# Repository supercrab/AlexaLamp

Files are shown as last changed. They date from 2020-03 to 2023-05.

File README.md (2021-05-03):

# AlexaLamp

This project was to create an Alexa voice controlled lamp with adjustable brightness. The lamp can also controlled using a rotary encoder with built in push switch or via a web page provided

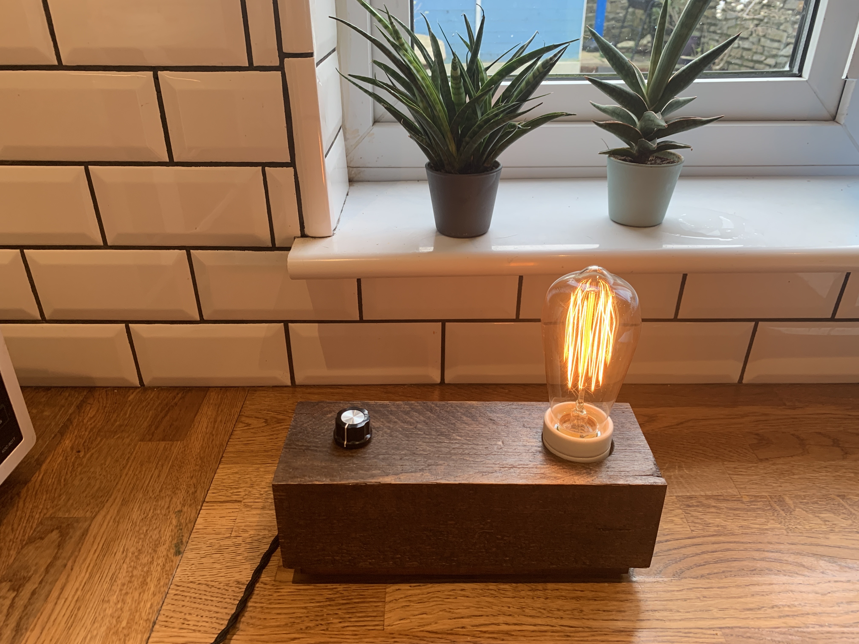
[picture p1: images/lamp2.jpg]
Lamp looking cool


## Components

Here is a list of the essential components you will need.  Shop around for the components as you should be able to find some good deals if you purchase from China/Banggood.

### Essential

* [Echo Dot](https://www.amazon.co.uk/Echo-Dot-3rd-Gen-Charcoal/dp/B07PJV3JPR) - for testing or final use but not mandatory as the lamp has a standalone mode and local website
* [Wemos D1 Mini or compatible](https://wiki.wemos.cc/products:d1:d1_mini) - I used a cheap clone
* [HLK-PM01 AC-DC 220V to 5v mini power supply module](http://www.hlktech.net/product_detail.php?ProId=54)
* [Robotdyn AC Light Dimmer Module](https://robotdyn.com/ac-light-dimmer-module-1-channel-3-3v-5v-logic-ac-50-60hz-220v-110v.html)
* [Rotary encoder with push switch](https://uk.pi-supply.com/products/rotary-encoder-push-switch) or [KY-040 rotary encoder module](https://uk.banggood.com/KY-040-Rotary-Decoder-Encoder-Module-AVR-PIC-p-914010.html)
* [Vintage E27 bulb holder ceramic](https://www.ebay.co.uk/itm/Vintage-E27-Bulb-Holder-Ceramic-Industrial-Lamp-Lighting-Antique-Retro-Edison/253903670767) you could use a bayonet holder if you preferred
* [MF-A03 control knob](https://www.google.com/search?q=MF-a03) or something similar
* [2 core twisted cable](https://www.ebay.co.uk/itm/2-Core-Twist-Braided-Fabric-Cable-Vintage-Electric-Wire-Flexible-Lighting-Cord/312959065511) because it's pretty
* [240v mains plug](https://www.ebay.co.uk/sch/i.html?_odkw=13A+BLACK+plug&_nkw=13A+fused+BLACK+plug) for UK builders

### Optional

These depend on how you are going to mount your bulb and what finish you fancy for your enclosure.

* [M10 hollow threaded rod](https://lightingspares.co.uk/collections/threaded-rods)
* [M10 threaded nut](https://lightingspares.co.uk/products/oaks-oa16-metal-10mm-threaded-nut)
* [M10 penny washer](https://www.toolstation.com/penny-washer/p90716)
* [Liberon based wood dye dark oak](https://www.screwfix.com/p/liberon-ethanol-based-wood-dye-dark-oak-250ml/3102f)
* [Liberon superior Danish oil clear](https://www.screwfix.com/c/decorating/wood-oil/cat850452)
* [Felt pads](https://www.toolstation.com/felt-gard-felt-pad-set/p95753)

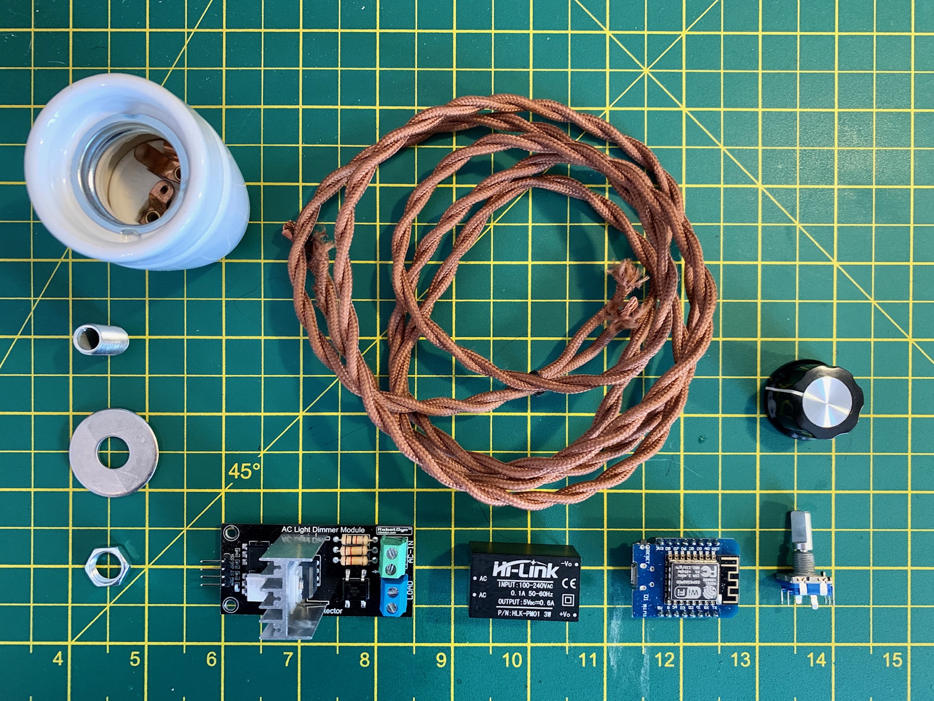
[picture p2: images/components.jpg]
Project components


## Schematic

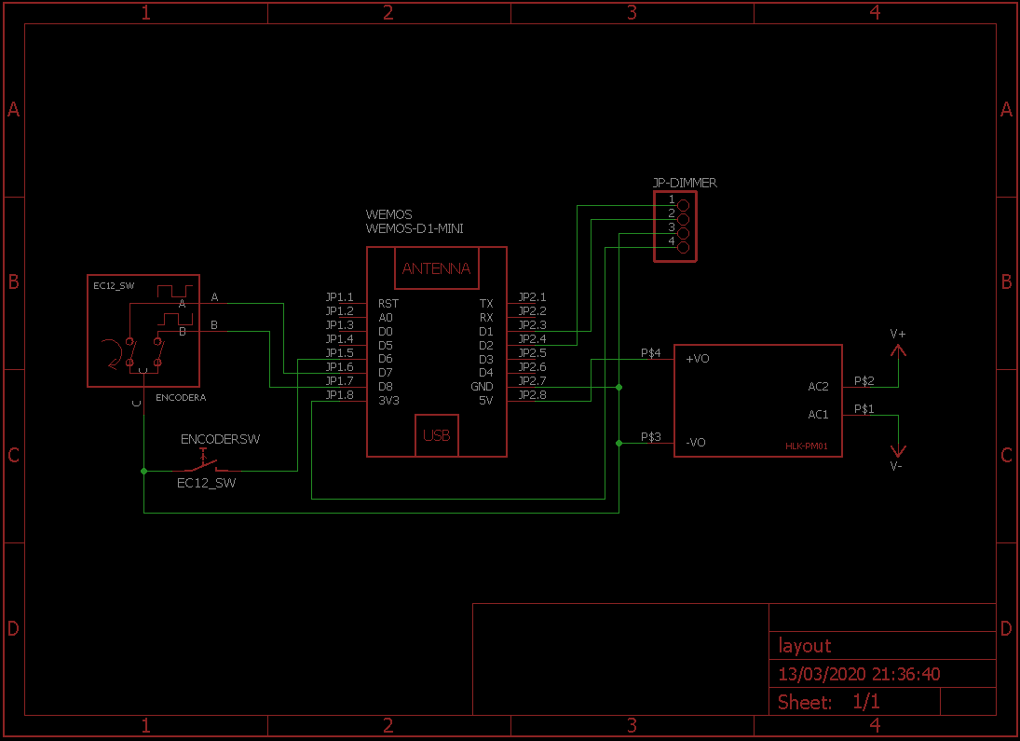
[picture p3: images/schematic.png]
Project schematic


**NOTE: the direction that the rotary encoder affects lamp brightness can be reversed by swapping digital inputs 6 & 7 or can be configured in the web front end**

## Wooden Enclosure

* The enclosure is made up of 2 parts: a wooden block (roughly 4 inches by 3 inches) and a planed wood base that screws into the block and locks the electronics away
* The wooden block is hollowed out so that there is enough space for all the components
* The components are arranged inside the cavity **ensure that wires carrying 240v are kept short and well away from the low voltage Wemos and dimmer control circuitry. The high voltage can cause flickering with brightness control if the wires were too close!**
* A cloth was used to apply 3 coats of [Liberon based wood dye dark oak](https://www.screwfix.com/p/liberon-ethanol-based-wood-dye-dark-oak-250ml/3102f) to give some colour.  You can also use [Liberon based wood dye light oak](https://www.screwfix.com/p/liberon-ethanol-based-wood-dye-light-oak-250ml/8322F) or mix them both dyes to create a new shade
* A peice of wirewool was used to apply 3 coats of [Liberon superior Danish oil clear](https://www.screwfix.com/c/decorating/wood-oil/cat850452) which gave the wood a shine and made it waterproof
* Once I was certain everything worked, the wooden base was screwed into the block and [felt pads](https://www.toolstation.com/felt-gard-felt-pad-set/p95753) were used to hide the screws
* If there is a problem you can always update the system over-the-air by navigating to the update page (http://lamp.local:81/update) and uploading a custom firmware (.bin file from the build process)

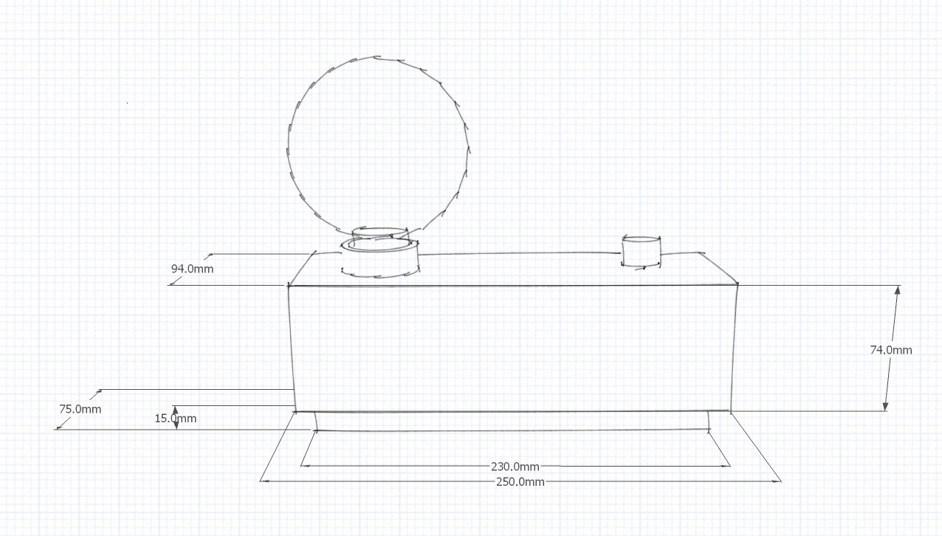
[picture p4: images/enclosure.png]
Project enclosure


## Instructions

* Build the circuit on a breadboard **be careful with the 240v side - turn it off when not in use**
* Download and install the following Arduino libraries
	* [Dimmable-Light-Arduino (Fabiano Riccardi)](https://github.com/fabiuz7/Dimmable-Light-Arduino)
	* [AsyncWiFiManager (lbussy)](https://github.com/lbussy/AsyncWiFiManager)
	* [Encoder (Paul Stoffregen)](https://github.com/PaulStoffregen/Encoder)
	* [JC_Button (Jack Christensen)](https://github.com/JChristensen/JC_Button)
	* [ESPAsyncWebServer (me-no-dev)](https://github.com/me-no-dev/ESPAsyncWebServer)
* Set IwIP Varaint: "v1.4 Higher Bandwidth"
* Set board to: D1 R2 & mini
* Download the AlexaLamp [code](https://github.com/supercrab/AlexaLamp), compile and upload code to Wemos D1 or compatible device
* Test everything works as expected (see below for how to setup wifi and change modes)
* Make the circuit permenant by installing into your wooden block or whatever space you have.

## How to use

The lamp has 2 modes: wifi (default) and standalone.  

To change the mode:

* Turn off the 240v supply to the lamp
* Hold the rotary encoder push switch down
* Turn on 240v supply
* Wait until the lamp starts to slowly flash
* Release the push switch
* The number of flashes seen will tell you which mode the lamp is in.  1 flash indicates standalone and 2 flashes for wifi/Alexa voice control mode.

### Wifi mode (default)

* When the lamp is turned on for the first time it will create an unsecured wifi hotspot called lamp-setup
* You can use your phone to connect to the hotspot and enter your wifi network credentials
* Once your credentials are verified, the hotspot will disappear and your wifi settings will be stored on the device
* The lamp will now connect to your network and you will be able to control the lamp using the rotary encoder
* Say "Alexa, discover devices" or go to the Alexa app and hit "Add Device", "Other", "Discover devices"
* Your lamp is now ready!

**If you connect the lamp to the mains and it cannot connect to a network using its stored settings then it will create a new hotspot and wait for new credentials.  While in this state, the rotary encoder will not work until the new wifi credentials are entered but you can still change the lamp's mode using the method described previously.**

### Standalone mode

* This mode does not connect to any wifi networks or create any hotspots
* Plain old lamp
* Rotary encoder works straight away

#### Lamp Webpages

* When in wifi mode you may navigate to lamp.local to access the lamp's web frontend.
* If you can't access the device this way then use a network discovery program to find the local IP address.

##### UI - Home Page

* Control state and brightness
* Change the device's Alexa name

#### UI - Settings

* Change mode: wifi or standalone
* Invert the rotary encoder, if you turning the knob does the opposite to what you want it to
* Change encoder knob sensitivity
* Change the frequency the device verifies its wifi connection.
* Enable atomatic updates (checked every 24 hours)

##### UI - Update

* Manually upload custom firmware (arduino .bin file) or start a remote update (if available)
* View the devices

##### UI - About

* Displays system version and information

### Alexa voice controls

Once setup, you can use different ways to invoke Alexa to modify the lamp's state:

* Alexa, turn lamp on
* Alexa, turn on lamp
* Alexa, set lamp to fifty (50% of brightness)
* Alexa, set lamp to one hundred (100% brightness)

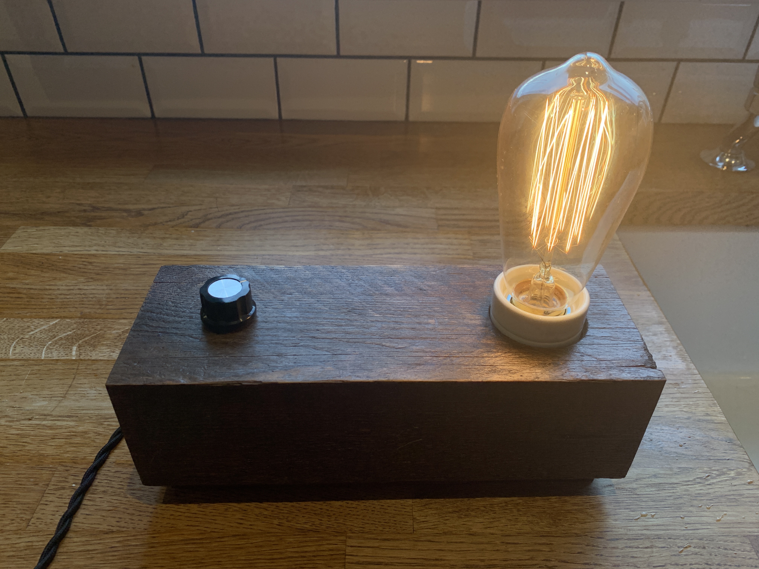
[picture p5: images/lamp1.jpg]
Lamp looking cool

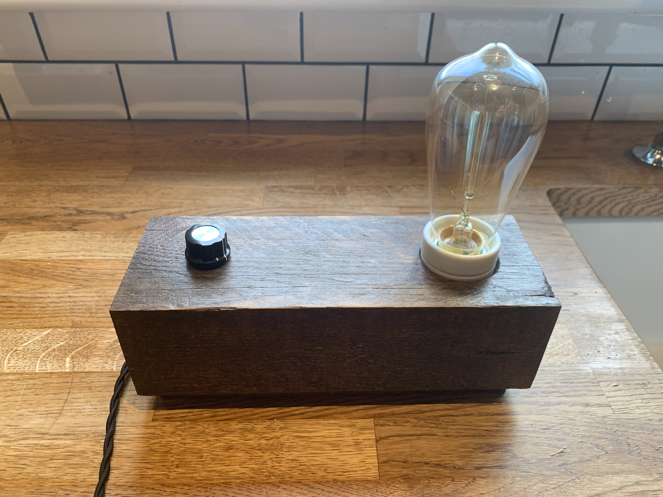
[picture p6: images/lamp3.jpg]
Lamp looking cool


# Credits

Developed on a WeMos D1 mini clone, using Arduino IDE 1.8.1 with ESP8266 Core 2.7.4

This project would not have been possible without the kind development of others on GitHub!  Click on a name to see the authors' GitHub page

* [Fauxmoesp (vintlabs)](https://github.com/vintlabs)
* [Encoder (Paul Stoffregen)](https://github.com/PaulStoffregen)
* [ESPAsncWebServer (me-no-dev)](https://github.com/me-no-dev)
* [AsynchWifiManager (lbussy)](https://github.com/lbussy)
* [JC_Button (Jack Christensen)](https://github.com/JChristensen)
* [Dimmable-Light-Arduino (Fabiano Riccardi)](https://github.com/fabiuz7)

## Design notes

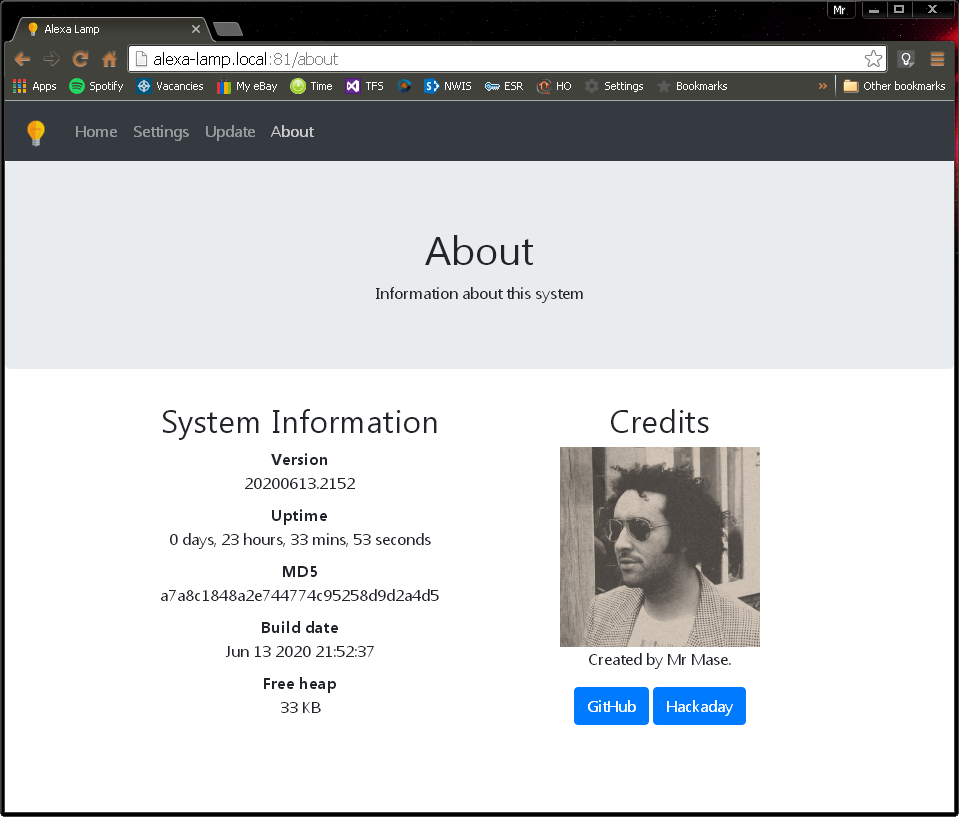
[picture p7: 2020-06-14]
images/web-about.png

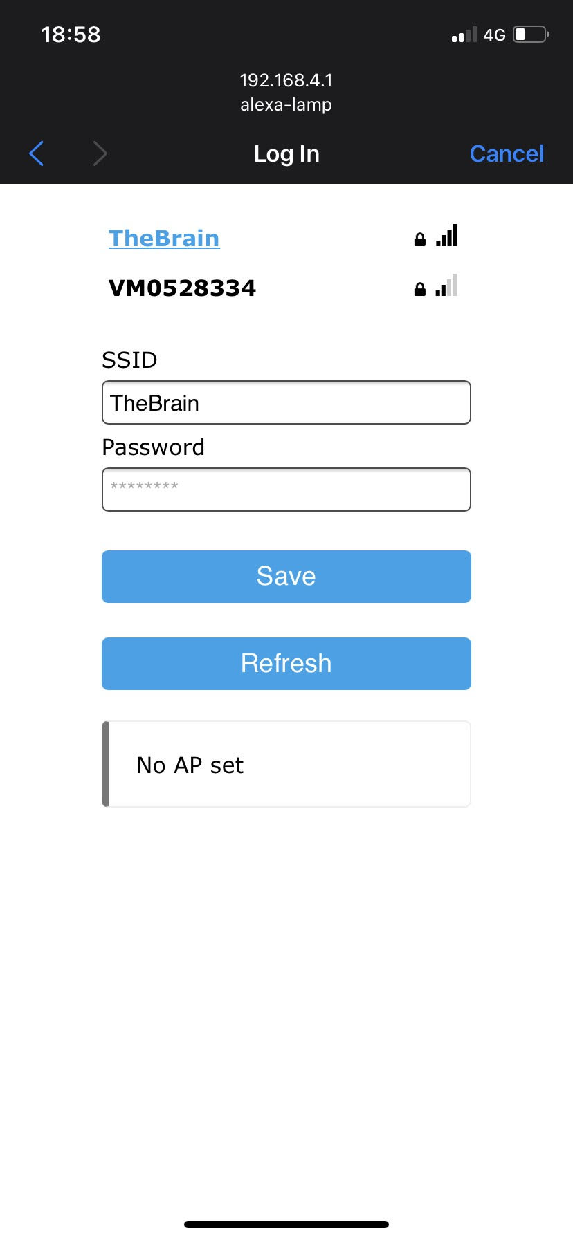
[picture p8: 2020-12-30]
images/wifi-manager-scan.jpg

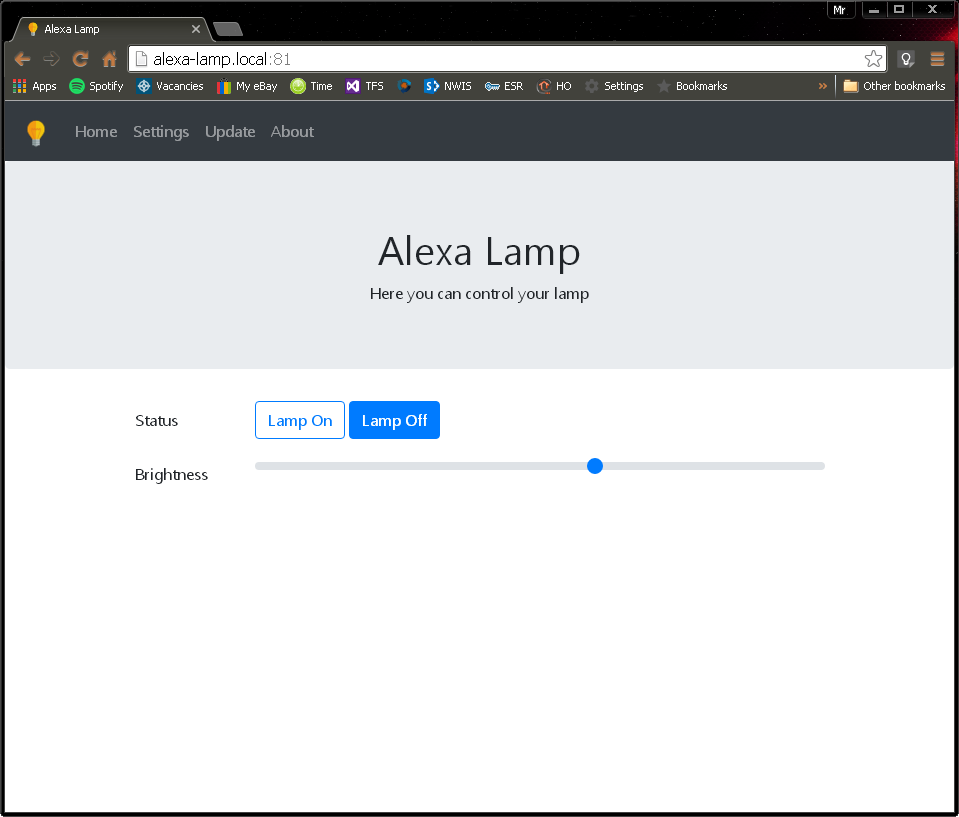
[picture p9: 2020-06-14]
images/web-home.png

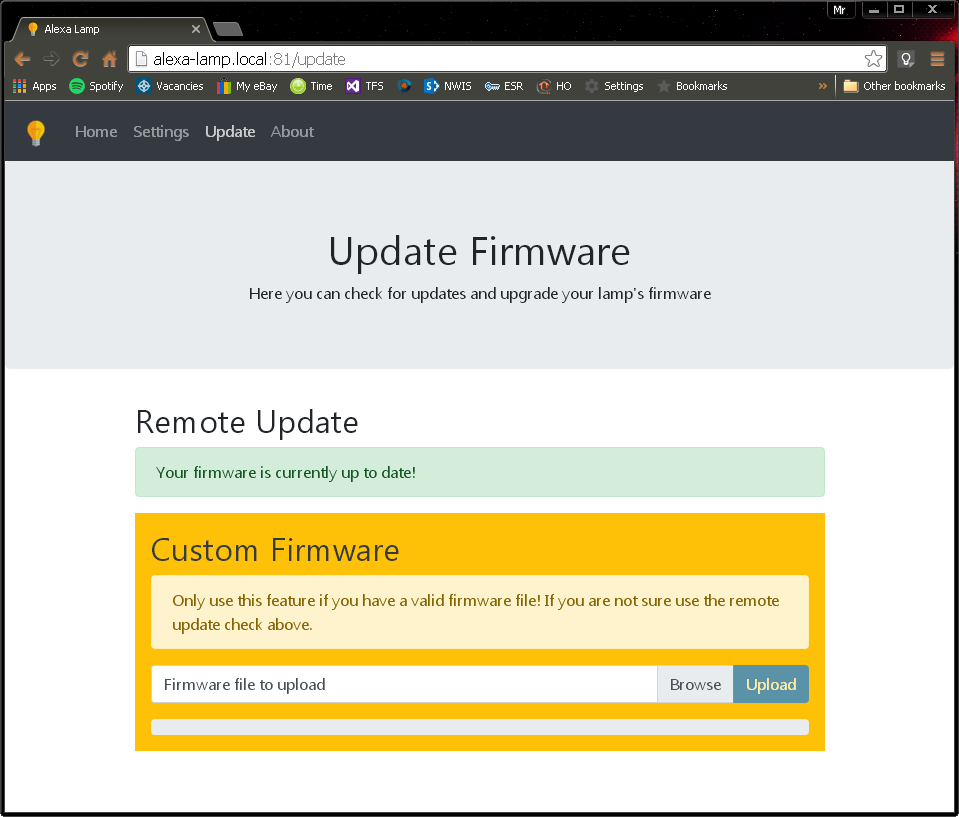
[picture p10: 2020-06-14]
images/web-update.png

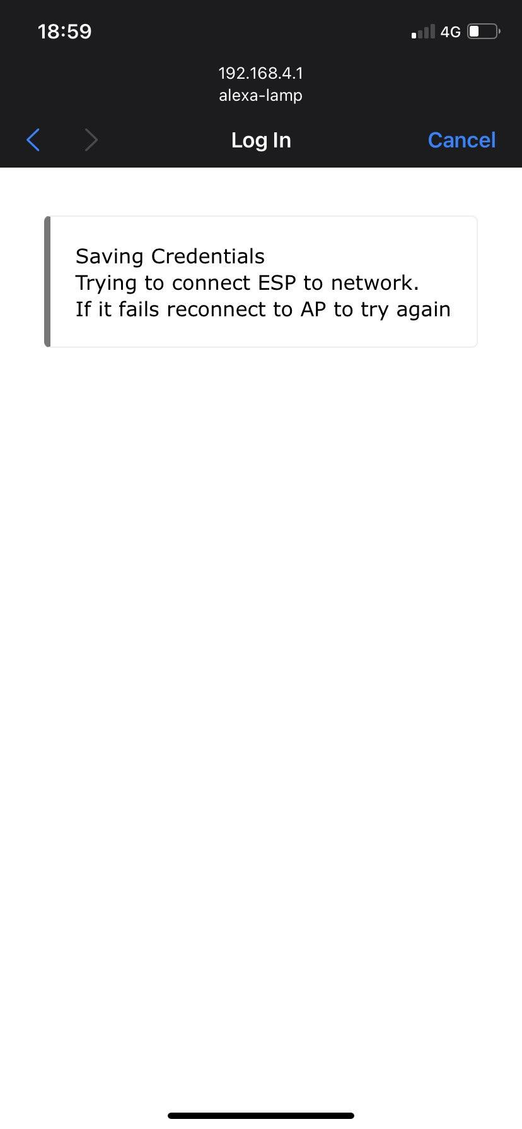
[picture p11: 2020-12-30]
images/wifi-manager-saving.jpg

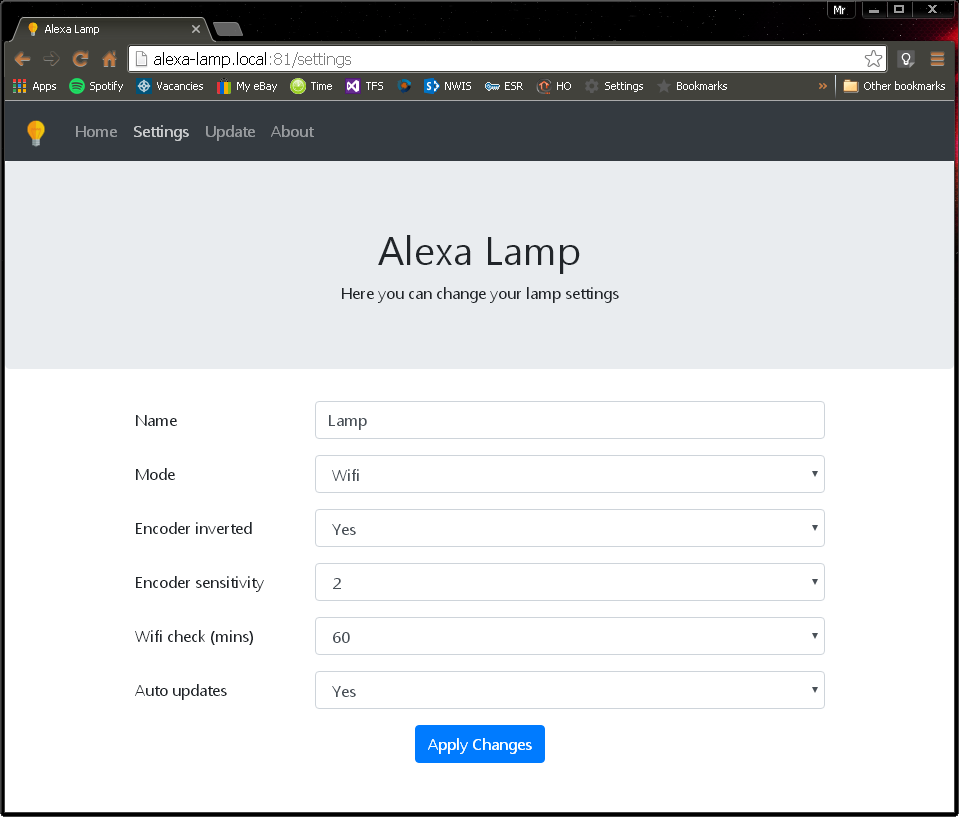
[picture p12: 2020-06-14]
images/web-settings.png

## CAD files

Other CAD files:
sketchup/enclosure.skp

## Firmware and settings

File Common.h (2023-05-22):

#ifndef Common_h
#define Common_h

// ---------------------------------------------------------
// Macros
// ---------------------------------------------------------

// Macro for calculating array length
#define ARRAY_LENGTH(array) (sizeof((array))/sizeof((array)[0]))

// ---------------------------------------------------------
// Hardware settings (these can be changed to match the hardware)
// ---------------------------------------------------------

// Zero cross detection pin
#define ZERO_CROSS_PIN	D1

// Triac pin 
#define TRIAC_PIN		D2 

// Encoder switch
#define ENCODER_SWITCH_PIN	D5

// Encoder A pin
#define ENCODER_A_PIN	D6

// Encode B pin 
#define ENCODER_B_PIN	D7

// ---------------------------------------------------------
// Default user settings - these can be changed
// ---------------------------------------------------------

// Initial device name for Alexa purposes 
#define DEFAULT_ALEXA_NAME	"Lamp"

// Initial mode can be WIFI or STANDALONE (WIFI is best)
#define DEFAULT_MODE WIFI

// How often should we check wifi is connected in minutes? (0, 1, 5, 15, 30, 60)
#define DEFAULT_WIFI_CONNECTED_CHECK_MINS 1

// How sensitive the encoder is 
// (1 = slowest, higher means more change)
#define DEFAULT_ENCODER_SENSITIVITY 2

// Default whether we want the encoder direction flipped
#define DEFAULT_ENCODER_INVERTED	false

// Default whether we want automatic updates (check period is defined above)
#define DEFAULT_AUTOMATIC_UPDATES	true

// ---------------------------------------------------------
// Initial lamp settings - these can be changed
// ---------------------------------------------------------

// Initial lamp brightness when turned on for the first time
#define INITIAL_BRIGHTNESS 255

// Initial lamp status (off for safety reasons)
#define INITIAL_STATE	false

// ---------------------------------------------------------
// Software settings - should not need changing
// ---------------------------------------------------------

// Enable MDNS
// The local URL for accessing the web config is http://lamp.local
// Running MDNS creates extra processing for the MDNS traffic
// If you're not bothered by having a MDNS name for the device then comment out this line
#define ENABLE_MDNS

// Serial baudrate 
#define SERIAL_BAUDRATE 115200

// Admin port for admin web page
#define ADMIN_WEB_PORT 81

// Define how many characters the device's alexa name can be
#define ALEXA_NAME_LENGTH	32

// Network hostname and for MDNS
#define HOSTNAME	"lamp"

// Access point created to configure Wifi settings
#define ACCESS_POINT_NAME "lamp-setup"

// Number of hours to check for automatic updates
#define AUTO_UPDATE_CHECK_PERIOD_HOURS 24

// ---------------------------------------------------------
// Remote update settings - should not be changed
// ---------------------------------------------------------

// Uodate server
#define HTTP_UPDATE_SERVER "supercrab.co.uk"

// Update path
#define HTTP_UPDATE_PATH "/update/"

// Device ID for http update
#define HTTP_UPDATE_DEVICE_ID "alexalamp"

// ---------------------------------------------------------
// Enums
// ---------------------------------------------------------

// Lamp mode
enum operation_t{
	STANDALONE, 
	WIFI
};

// Holds current update status
enum updateStatus_t{
	UPDATE_STATUS_IDLE,				// 0 - not updating
	UPDATE_STATUS_NO_UPDATES,		// 1 - checked for updates but there were nonte
	UPDATE_STATUS_LOCAL_UPDATE,		// 2 - update by an uploaded firmware
	UPDATE_STATUS_REMOTE_UPDATE,	// 3 - update by checking remote server
	UPDATE_STATUS_FAILED,			// 4 - update failed
	UPDATE_STATUS_OK				// 5 - updated worked
};

#endif

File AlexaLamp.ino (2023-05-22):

//	____ _    ____ _  _ ____       _    ____ _  _ ___  
//	|__| |    |___  \/  |__|       |    |__| |\/| |__] 
//	|  | |___ |___ _/\_ |  |       |___ |  | |  | |    
//				with brightness control
//
//	by Supercrab
//	https://github.com/supercrab
//
//	Developed on a WeMos D1 mini clone, using Arduino IDE 1.8.1 with ESP8266 Core 2.7.4
//
//  This code is intended to work on cheap ESP8266 devices
//
//	Thanks to the developers of the libraries I found on GitHub!
//
// TODO
// ====
// 
// * Lamp might flickers with values < 100, this seems to be down to the newer ESP core
// * MDNS seems to be flakey especially after you setup wifi using the automatic hotspot
//   hopefully fixed in a newer version of the ESP8266 core (not related to any code here)
// * Fauxmo - when 2 devices have the same Alexa name and you browse to the device on port 80, it causes a restart
//  (might be fixed due to the MAC address not being static now)
//
// ---------------------------------------------------------
// Main configuration
// ---------------------------------------------------------
#include "Common.h"

// ---------------------------------------------------------
//  * Fauxmoesp (vintlabs)
//  https://github.com/vintlabs/fauxmoESP
//	* Fauxmoesp redirect functionality (Enrico A.)
//	https://bitbucket.org/xoseperez/fauxmoesp/issues/101/fauxmoesp-with-esp8266webserver
// ---------------------------------------------------------
#include "fauxmoESP.h"

// ---------------------------------------------------------
//	* Dimmable-Light-Arduino (Fabiano Riccardi)
//	https://github.com/fabiuz7/Dimmable-Light-Arduino
// ---------------------------------------------------------
#include <dimmable_light.h>

// ---------------------------------------------------------
//	* AsyncWiFiManager (lbussy)
//	https://github.com/lbussy/AsyncWiFiManager
// ---------------------------------------------------------
#define WM_ASYNC // Turn on Async mode
#include <AsyncWiFiManager.h>

// ---------------------------------------------------------
//	* Encoder (Paul Stoffregen)
//	https://github.com/PaulStoffregen/Encoder
// ---------------------------------------------------------
#include <Encoder.h>

// ---------------------------------------------------------
//	* JC_Button (Jack Christensen)
//	https://github.com/JChristensen/JC_Button
// ---------------------------------------------------------
#include <JC_Button.h>

// ---------------------------------------------------------
// System libraries
// ---------------------------------------------------------
#ifdef ENABLE_MDNS
	#include <ESP8266mDNS.h>
#endif
#include <ESP8266HTTPClient.h>
#include "coredecls.h"

// ---------------------------------------------------------
// Project libraries
// ---------------------------------------------------------
#include "SoftwareTimer.h"
#include "Config.h"
#include "AdminWebServer.h"
#include "HttpUpdate.h"

fauxmoESP fauxmo;
DimmableLight light(TRIAC_PIN);
Encoder encoder(ENCODER_A_PIN, ENCODER_B_PIN);
Button button(ENCODER_SWITCH_PIN);
SoftwareTimer timerWifiCheck;
SoftwareTimer timerAutomaticUpdate;
AdminWebServer server(ADMIN_WEB_PORT);
Config config;

// Calculate PWM constant
const float pwm = (255 * log10(2))/log10(255);

// Previous encoder value
int16_t encoderOldValue = 0;

// Initialise serial port and communications
void setupSerial(){
	Serial.begin(SERIAL_BAUDRATE);
	Serial.println();
	Serial.println();
	Serial.println(F("-----------------------------------"));
	Serial.println(F("Application started"));
	Serial.println(F("-----------------------------------"));
	Serial.println();
}

// Set the brightness based on a correction for non linear brightness
// https://diarmuid.ie/blog/pwm-exponential-led-fading-on-arduino-or-other-platforms
void setLightBrightness(uint8_t value){
	uint8_t brightness = correctPwmBrightness(value);
	light.setBrightness(brightness);
}

// Function to correct for non linear brightness when using PWM
//
// Works but the light was practically off at brightness value 100
// Needs some sort of light calibration which is probably different for all bulbs, so disabled for now
uint8_t correctPwmBrightness(uint8_t value){
	return value;
	/*
	if (value == 255) {
		return 255;
	}
	return pow(2, (value / pwm)) - 1;
	*/
}

// Callback for when remote update starts
void remoteUpdateStarted() {
	Serial.println(F("UPDATE: HTTP update process started"));
}

// Callback for when remote update completes
void remoteUpdateFinished() {
	Serial.println(F("UPDATE: HTTP update process finished"));

	// Store current lamp state so that we can restart and return to what the lamp was doing
	config.systemUpdated();

	// Turn light off before restarting because the light (timer) becomes unstable
	setLightBrightness(0);
}

// Info on using the updater class:
// https://arduino-esp8266.readthedocs.io/en/latest/ota_updates/readme.html
// https://github.com/esp8266/Arduino/blob/16319da63d4e8f7b4d029bfe667ed1b370a485bb/doc/ota_updates/readme.rst
// 
// My changes to the ESP8266 WebUpdater:
//
// 1. New method on web updater to prevent an update if we just want to check if one is available
t_httpUpdate_return update(bool install){

	// Flash our built in LED
	ESPhttpUpdate.setLedPin(LED_BUILTIN, LOW);

	// Set if we actually want to install the update if there is one
	ESPhttpUpdate.installUpdate(install);

	// If we're installing the update, set a callback to let the main program know the update has finished
	if (install){
		ESPhttpUpdate.onStart(remoteUpdateStarted);
		ESPhttpUpdate.onEnd(remoteUpdateFinished);
	}
	
	// Old way - works perfectly but is deprecated 
	t_httpUpdate_return ret = ESPhttpUpdate.updateNew(HTTP_UPDATE_DEVICE_ID, HTTP_UPDATE_SERVER, 80, HTTP_UPDATE_PATH);

	// New way - no worky, gives me a 301 (moved permenantly error), probably my host
	/*
	WiFiClient client;
	t_httpUpdate_return ret = ESPhttpUpdate.update(client, "http://supercrab.co.uk/update");
	*/

	// Handle returned result
	switch(ret) {
		case HTTP_UPDATE_AVAILABLE: 

			// This code is only executed when install = false
			// If install = true, then the system is updated and rebooted before it gets here
			Serial.println(F("UPDATE: available!"));
			break;

		case HTTP_UPDATE_FAILED:

			// Update was available but it failed
			Serial.println(F("UPDATE: failed!"));
			Serial.println(ESPhttpUpdate.getLastErrorString());
			if (install){
				config.setUpdateStatusFailed(ESPhttpUpdate.getLastErrorString());
			}
			break;

		case HTTP_UPDATE_NO_UPDATES:

			// There are not updated
			Serial.println(F("UPDATE: not available"));
			if (install){
				config.setUpdateStatusNoUpdates();
			}
			break;

		case HTTP_UPDATE_OK:
			// Here for completeness as this is not called because
			// a successful update causes the system to be rebooted)
			break;
	}
	return ret;
}

// Pulse the light 
void pulseLight(uint8_t times = 1){

	for (uint8_t t = 0; t < times; t++){

		// Ramp brightness up
		for (uint8_t b = 0; b < 255; b++){
			light.setBrightness(b);
			delay(6);
		}

		// Wait a bit at maximum
		delay(250);

		// Ramp brightness down
		for (uint8_t b = 255; b > 0; b--){
			light.setBrightness(b);
			delay(6);
		}
	}
}

// Setup hostname
void setupHostname(){

	Serial.print(F("WIFI: setting up hostname: ")); Serial.println(HOSTNAME);

	// Set the network host name
	WiFi.hostname(HOSTNAME);
}

// Callback when connecting to previous WiFi fails
void wifiManagerCallback(AsyncWiFiManager *myWiFiManager) {

	Serial.println(F("WIFI: entered configuration mode, creating access point"));
	Serial.println(WiFi.softAPIP());
	Serial.println(myWiFiManager->getConfigPortalSSID());
}

// Setup MDNS
void setupMDNS(){

	// Try and give us a name MDNS
	Serial.print(F("MDNS: setting up host as ")); 
	Serial.print(HOSTNAME);
	Serial.println(F(".local"));

	MDNS.close();
	if (!MDNS.begin(HOSTNAME)) {
		Serial.println(F("MDNS: failed"));
	}
	else{
		// Broadcast our http web server on admin port
		MDNS.addService("http", "tcp", ADMIN_WEB_PORT);
		Serial.println(F("MDNS: OK!"));
	}
}

// Setup Wifi
void setupWifiManager() {

	Serial.println(F("WIFI: starting connection manager"));

	// AsyncWiFiManager intialization. Once its business is done, there is no need to keep it around
	AsyncWiFiManager wifiManager;

	// set callback that gets called when connecting to previous WiFi fails, and enters Access Point mode
	wifiManager.setAPCallback(wifiManagerCallback);

	// fetches ssid and pass and tries to connect
	// if it does not connect it starts an access point with the specified name
	// and goes into a blocking loop awaiting configuration
	if (!wifiManager.autoConnect(ACCESS_POINT_NAME)){

		Serial.println(F("WIFI: failed to connect and hit timeout"));

		// reset and try again, or maybe put it to deep sleep
		ESP.restart();
		delay(1000);
	} 
	else {
		// The wifi manager has connected us!
		Serial.printf("WIFI: OK!  SSID: %s, IP address: %s\n", WiFi.SSID().c_str(), WiFi.localIP().toString().c_str());
	}
}

// Setup rotary encoder button
void setupButton(){
	button.begin();
}

// Setup rotary encoder
void setupRotaryEncoder(){
	setEncoderValue();
}

// Setup dimmer
void setupDimmer(){
	static bool dimmerInitialised = false;

	// only update dimmer if not updated
	if (!dimmerInitialised){
		DimmableLight::setSyncPin(ZERO_CROSS_PIN);
		DimmableLight::begin();
		dimmerInitialised = true;
	}
}

// Setup fauxmo library
void setupFauxmo(){

	fauxmo.createServer(true); 
	fauxmo.setPort(80); // for Gen3 devices
	fauxmo.setRedirect(ADMIN_WEB_PORT); // custom method to direct HTTP traffic on port 80 to custom port
	fauxmo.enable(true);

	// Add virtual device
	fauxmo.addDevice(config.getDeviceName());

	// Lamda expresison to handle light control  
	fauxmo.onSetState([](byte deviceId, const char* deviceName, bool deviceState, unsigned char value){

		// Output what we received
		Serial.printf("FAUXMO: device ID #%d (%s) state: %s value: %d\n", deviceId, deviceName, deviceState ? "ON " : "OFF", value);
		
		// Is the device matched?
		if (strcmp(deviceName, config.getDeviceName()) == 0) {

			// Store light state
			config.setState(deviceState);

			// Store light brightness
			config.setBrightness(value);

			// Set light brightness
			setLightBrightness(config.getState() ? config.getBrightness() : 0);

			// Set the rotary encolder value to current brightness (invert if required)
			setEncoderValue();
		} 
	});

	Serial.print(F("FAUXMO: initiated device called: "));
	Serial.println(config.getDeviceName());
}

// Setup webserver
void setupWebServer(){
	server.begin(&config);
}

// Setup a timer to periodically check wifi status
void setupWifiCheckTimer(){

	// Lambda expersion  to check wifi status is connected 
	timerWifiCheck.setCallback([](void){
		
		Serial.print("WIFI STATUS: ");

		// Check wifi status
		if (WiFi.status() != WL_CONNECTED){

			Serial.println("BAD!  Restarting device...");

			// Restart board and try and reconnect or enter AP mode
			ESP.restart();

			// Wait a while for the restart to kick in
			delay(5000);
		}
		else{
			Serial.println("OK");
		}
	});

	// Set the timer interval and start
	timerWifiCheck.setIntervalMinutes(config.getWifiCheckInterval()); 
	timerWifiCheck.start();
}

// Setup a timer to periodically check for automatic updates
void setupAutomaticUpdateTimer(){

	// Lambda expersion to run automatic update check
	timerAutomaticUpdate.setCallback([](void){

		// Check update - if update does occur the system is automatically restarted
		Serial.println(F("AUTO UPDATE: checking!"));
		updateSystem();
	});

	// Set the timer interval and start
	timerAutomaticUpdate.setIntervalHours(config.getAutomaticUpdates() ? AUTO_UPDATE_CHECK_PERIOD_HOURS : 0); 
	timerAutomaticUpdate.start();
}

// Reboot the system
void rebootSystem(){

	Serial.println(F("Rebooting..."));

	// Disable server
	server.end();
	
	// Wait for web connections to stop
	delay(250);

	// Restart
	ESP.restart();

	// Wait for restart to kick in
	delay(5000);
}

// Check and update system
void updateSystem(){

	Serial.println(F("UPDATE SYSTEM: checking and installing updates..."));

	// If we are doing an automatic update then we need to set our update status
	// This is also set in the web server layer when user visits the updatenow webpage
	config.setUpdateStatusRemoteUpdate();

	// Wait for any web connections to finish
	delay(250);

	// If update does occur the system is automatically restarted
	update(true);
}

// Update the light
void updateLight(){

	// Set the brightness!
	setLightBrightness(config.getState() ? config.getBrightness() : 0);

	// Reset rotary encoder to current brightness
	// (this prevents rotary encoder affecting brightness when light is off)
	setEncoderValue();

	// Broadcast light state
	updateAlexa();
}

// Broadcast light state to alexa
void updateAlexa(){

	// Only update fauxmo if wifi is enabled
	if (config.getMode() == WIFI){
		fauxmo.setState(config.getDeviceName(), config.getState(), config.getBrightness());
	}
}

// Update settings - called when web server adjusts settings
void updateSettings(){

	// Update light just in case state or brightness has been changed
	updateLight();

	if (config.getMode() == WIFI){

		// Adjust timers
		timerWifiCheck.setIntervalMinutes(config.getWifiCheckInterval());
		timerAutomaticUpdate.setIntervalHours(config.getAutomaticUpdates() ? AUTO_UPDATE_CHECK_PERIOD_HOURS : 0); 

		// Adjust fauxmo name
		fauxmo.renameDevice((byte) 0, config.getDeviceName());
	}
	else {

		// Prevent WIFI auto connecting when device is restarted
		WiFi.setAutoConnect(false);

		// Disable timers
		timerWifiCheck.stop();
		timerAutomaticUpdate.stop();

		// Stop fauxmo
		fauxmo.enable(false);

#ifdef ENABLE_MDNS
		// Stop MDNS
		MDNS.close();
#endif
		// Destroy web server
		server.end();
	}
}

// Invert encoder direction
void invertEncoder(){
	encoderOldValue = 255 - encoder.read();
	encoder.write(encoderOldValue);
}

// ---------------------------------------------------------
// Setup
// ---------------------------------------------------------
void setup() {

	// This line disables the automatic ESP access point, e.g. ESP-xxxxx
	WiFi.mode(WIFI_STA);

	// https://github.com/me-no-dev/ESPAsyncWebServer/issues/716
	// ISSUE: using char arrays causes resets
	// FIX: prevent re-use of the OS stack
	disable_extra4k_at_link_time();

	setupSerial();

	// Initialse/load settings from EEPROM
	config.begin();

	// Button setup
	setupButton();

	// Dimmer setup
	setupDimmer();

	// Pass methods into config which will update the main thread 
	config.onLightChanged(updateLight);
	config.onSettingsChanged(updateSettings);
	config.onEncoderInverted(invertEncoder);

	// Change mode?
	if (button.read()){

		// Flip wifi mode
		config.toggleMode();

		// Save the settings
		config.save();

		// If WIFI has been disabled then prevent WIFI auto connecting when device is restarted
		if (config.getMode() != WIFI){
			WiFi.setAutoConnect(false);
		}

		// Pulse light to (twice = wifi on, once = wifi off)
		pulseLight(config.getMode() == WIFI ? 2 : 1);

		// Clear the previous button press!
		setupButton();
	}

	// Is light in Wifi mode?
	if (config.getMode() == WIFI) {

		Serial.println(F("WIFI: starting setup"));

		// Setup hostname
		setupHostname();

		// Setup wifi manager
		setupWifiManager();

#ifdef ENABLE_MDNS
		// Setup MSDNS
		// This takes a couple of minutes to work if the Wifi manager has been invoked
		// and the device has just configure to connect to a new WIFI network
		setupMDNS();
#endif

		// Setup fauxmo
		setupFauxmo();

		// Setup webserver
		setupWebServer();

		// Setup the wifi connected check
		setupWifiCheckTimer();

		// Setup automatic update check
		setupAutomaticUpdateTimer();
	}
	else {
		Serial.println(F("WIFI: disabled"));
	}

	// Setup rotary encoder (this caused issues when called sooner)
	setupRotaryEncoder();

	// Lamp is on after a system update so broadcast its state and update encoder
	if (config.getState()){
		updateLight();
	}

	Serial.println(F("SETUP: finished"));
}

// Set the encoder value depending on current brightness and encoder inverted setting
void setEncoderValue(){

	// Setting the encoder value prevents an uncessary change in the encoder being picked up in the main loop
	encoderOldValue = config.getEncoderInverted() ? 255 - config.getBrightness() : config.getBrightness();
	encoder.write(encoderOldValue);
}

// ---------------------------------------------------------
// Loop
// ---------------------------------------------------------
void loop() {

	// Do we need to reboot the system after a firmware upload or reboot call?
	// Reboot needs to be called from outside of the web request handling
	if (config.getRebootSystem()){
		rebootSystem();
	}

	// Have we been asked to do an upate by the web server?
	if (config.getUpdateStatus() == UPDATE_STATUS_REMOTE_UPDATE){
		updateSystem();
	}

	// Is the light in WiFi mode?
	if (config.getMode() == WIFI){

#ifdef ENABLE_MDNS
		// Need this for MDNS to work
		MDNS.update();
#endif
		// Periodically check if Wifi is connected 
		timerWifiCheck.handle();

		// Periodically check if any updates are available
		timerAutomaticUpdate.handle();

		// fauxmoESP uses an async TCP server but a sync UDP server
		// Therefore, we have to manually poll for UDP packets
		fauxmo.handle();
	}

	// Read button presses
	button.read();

	// Turn light on or off if button has been pressed
	if (button.wasPressed()){

		// Flip light state
		config.toggleState();

		// Set the brightness!
		setLightBrightness(config.getState() ? config.getBrightness() : 0);

		// Reset rotary encoder to current brightness
		// (this prevents rotary encoder affecting brightness when light is off)
		setEncoderValue();

		// Broadcast light state
		updateAlexa();

		Serial.printf("Button pressed!  State: %s value: %d\n", config.getState() ? "ON" : "OFF", config.getBrightness());
	}

	// If light is on allow rotary encoder to change brightness
	if (config.getState()){

		// Calculate new value with sensitivity factor
		int16_t encoderNewValue = encoderOldValue - ((encoderOldValue - encoder.read()) * config.getEncoderSensitivity());

		// Enforce rotary encoder maximum value
		if (encoderNewValue > 255){
			encoderNewValue = 255;
			encoder.write(encoderNewValue);	
		}

		// Enforce rotary encoder minimum value
		else if (encoderNewValue < 0){
			encoderNewValue = 0;
			encoder.write(encoderNewValue);	
		}

		// Rotary encoder has changed so change brightness
		if (encoderNewValue != encoderOldValue) {

			// Set encoder value if not on default sensitivity
			if (config.getEncoderSensitivity() > 1){
				encoder.write(encoderNewValue);	
			}

			// Store brightness depending on whether we need to invert the encoder
			config.setBrightness(config.getEncoderInverted() ? 255 - encoderNewValue : encoderNewValue);

			// Set light brightness
			setLightBrightness(config.getBrightness());

			// Broadcast light state
			updateAlexa();

			// Store the old value
			encoderOldValue = encoderNewValue;
		}
	}
}

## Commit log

2020-03-14 Added eagle libraries used to create schematic
2020-08-08 Update AlexaLamp.ino
    Fixed hard software limit on rotary encoder
    [AlexaLamp.ino]
2021-01-12 Added fixes to improve wifi functionality
    [AdminWebServer.cpp, AlexaLamp.ino, Common.h]
2021-05-02 Fixed a couple of bugs I had noticed
    Fixed Alexa not finding devices by upgrading fauxmo library
    Fixed update page not redirecting
    Fixed progress bar not correct size
    [AdminWebServer.cpp, AlexaLamp.ino, Common.h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]
2023-05-22 Refresh
    Changed GUI for displaying updates
    Added experiments for linear PWM fix but commented out
    [AdminWebServer.cpp, AlexaLamp.ino, Common.h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]
